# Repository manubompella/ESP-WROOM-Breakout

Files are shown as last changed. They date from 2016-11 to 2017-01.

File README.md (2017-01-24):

# ESP-WROOM-Breakout
Breakouts for ESP8266 and ESP32 WiFi/WLAN + Bluetooth modules from Espressif.
*Note: AI-Thinker ESP-13 is compatible with Espressif ESP-WROOM-02 and AI-Thinker ESP-32S is compatible with Espressif ESP-WROOM-32.*

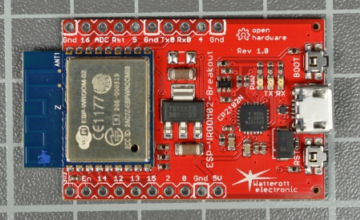
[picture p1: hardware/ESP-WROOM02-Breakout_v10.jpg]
ESP-WROOM02-Breakout (http://www.watterott.com/en/ESP-WROOM02-Breakout)

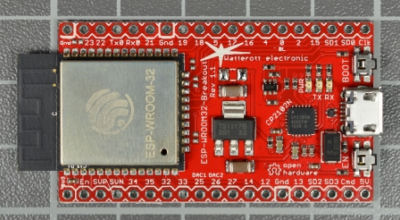
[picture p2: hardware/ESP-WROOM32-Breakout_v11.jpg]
ESP-WROOM32-Breakout (http://www.watterott.com/en/ESP-WROOM32-Breakout)


## Shop
* [ESP-WROOM-02-Breakout (ESP8266)](http://www.watterott.com/en/ESP-WROOM02-Breakout)
* [ESP-WROOM-32-Breakout (ESP32)](http://www.watterott.com/en/ESP-WROOM32-Breakout)

## Features
* Espressif [ESP8266 ESP-WROOM-02](http://espressif.com/en/products/hardware/esp8266ex/overview) WiFi module
* Espressif [ESP32 ESP-WROOM-32](http://espressif.com/en/products/hardware/esp32/overview) WiFi+Bluetooth module
* WiFi standard: IEEE 802.11b/g/n 2.4GHz
* WiFi security: WEP, WPA, WPA2, WAPI
* WiFi Direct and Soft-AP (Access-Point mode)
* Classic and BLE Bluetooth (ESP32)
* Silabs [CP2102N](http://www.silabs.com/products/interface/usb-bridges/usbxpress-usb-bridges/Pages/usbxpress-usb-bridges.aspx) USB UART Bridge (up to 3M baud)
* microUSB-Connector

## Hardware and Software
* [Schematics + Layout](https://github.com/watterott/ESP-WROOM-Breakout/tree/master/hardware)
* ESP8266: [Arduino Core](https://github.com/esp8266/Arduino) (Board: NodeMCU v1)
* ESP32: [Arduino Core](https://github.com/espressif/arduino-esp32) (Board: ESP32 Dev Module)
* [Silabs Serial Port Driver (VCP)](http://www.silabs.com/products/mcu/pages/usbtouartbridgevcpdrivers.aspx)

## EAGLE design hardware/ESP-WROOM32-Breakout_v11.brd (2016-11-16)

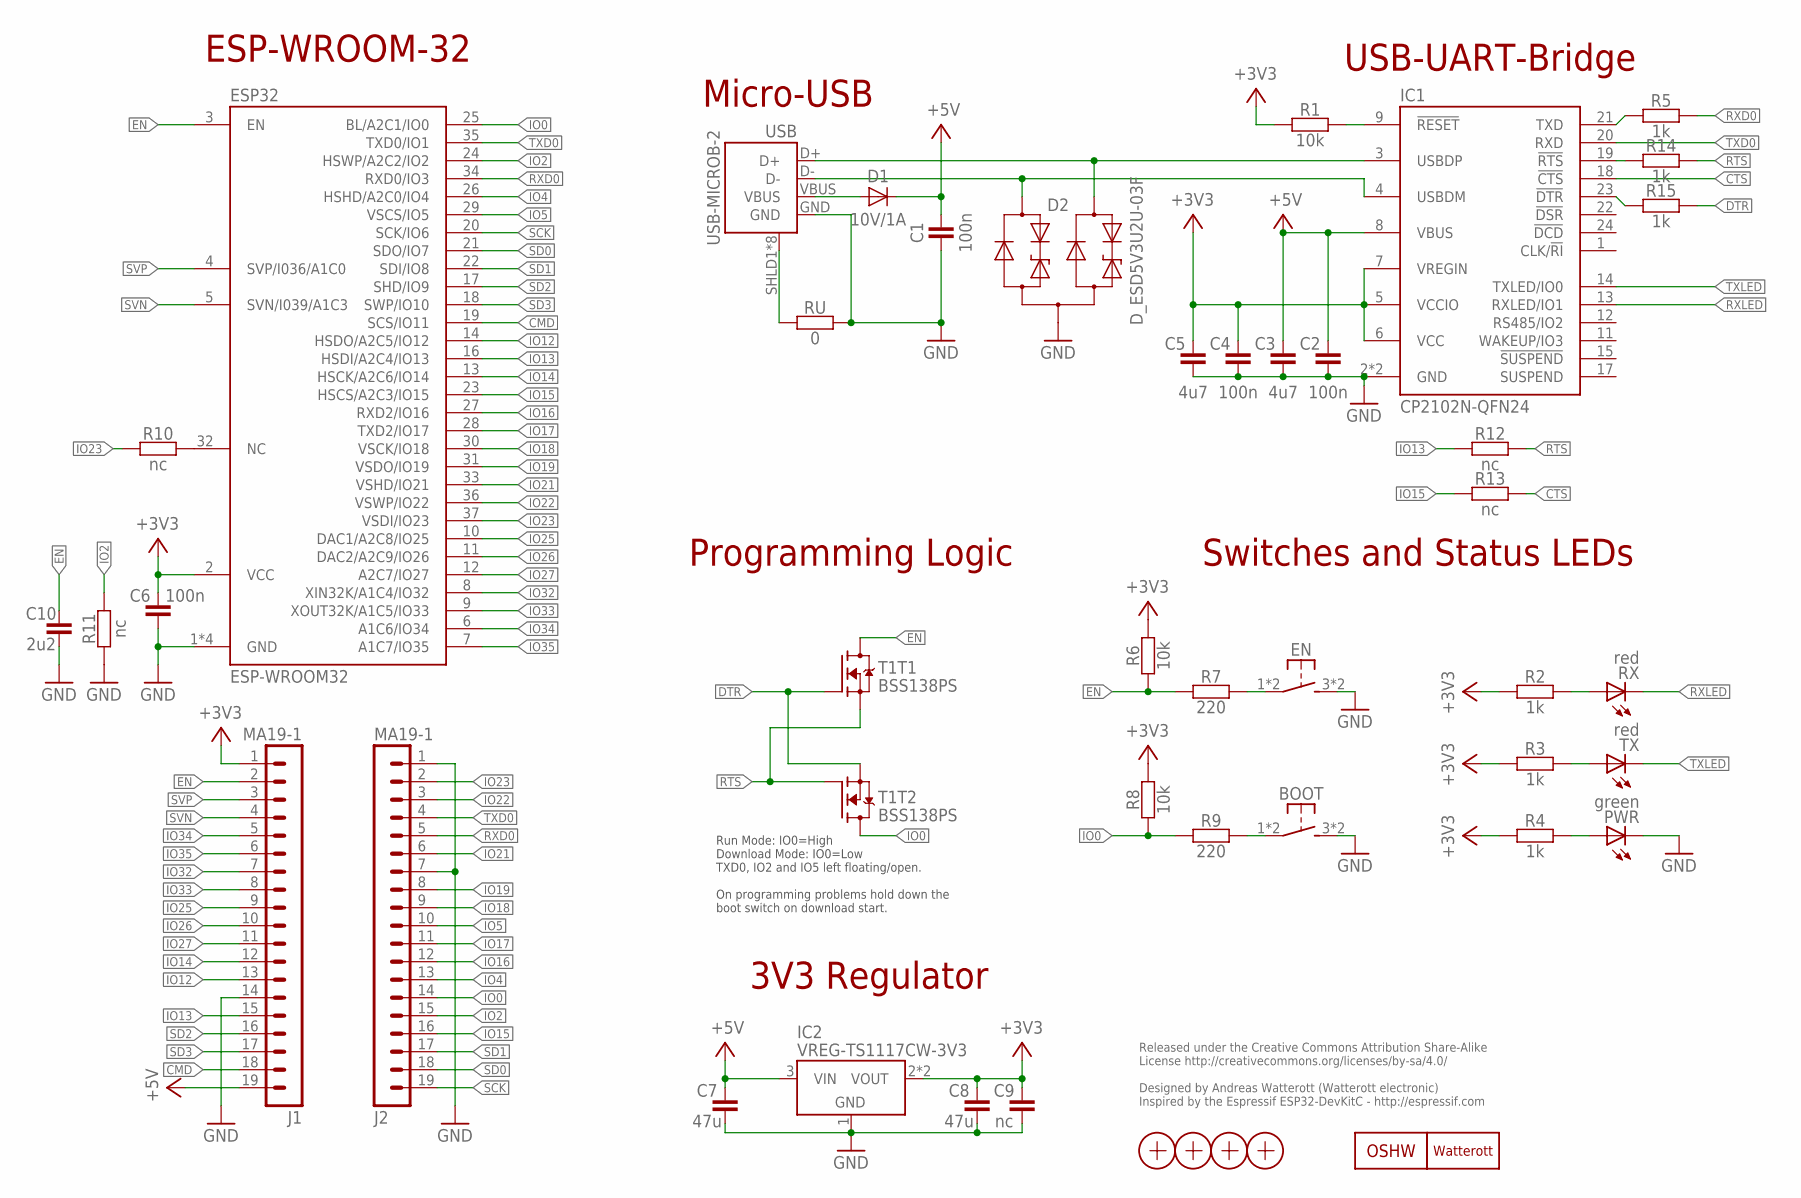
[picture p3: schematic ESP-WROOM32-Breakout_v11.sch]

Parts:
BOOT: SW-TACTILE-PTS840P; PTS840P
C1, C2, C4, C6: 100n; C0402
C3, C5: 4u7; C0603
C7, C8: 47u; C1206
C9: nc; C1206
C10: 2u2; C0402
D1: 10V/1A; SMA_DO214AC
D2: D_ESD5V3U2U-03F; SOT723
EN: SW-TACTILE-PTS840P; PTS840P
ESP32: ESP-WROOM32
IC1: CP2102N-QFN24; QFN24-PAD
IC2: VREG-TS1117CW-3V3; SOT223
J1, J2: MA19-1
LOGO2: OSHW_LOGOX0070; OSHW_6X70
LOGO4: LOGO-S_PLACE_M; SPARK_TPLACE_M
PWR: green; C0603
R1, R6, R8: 10k; C0402
R2, R3, R4, R5, R14, R15: 1k; C0402
R7, R9: 220; C0402
R10, R11, R12, R13: nc; C0402
RU: 0; C0402
RX: red; C0603
T1: BSS138PS; SOT363
TX: red; C0603
USB: USB-MICROB-2; USB-MICROB-10118194
X1, X2, X3, X4: PASSER-07; PASSER_07MM

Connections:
+3V3: C4.2, C5.2, C6.2, C8.2, C9.2, ESP32.2 (VCC), IC1.5 (VCCIO), IC1.6 (VCC), IC1.7 (VREGIN), IC2.2 (VOUT), IC2.4 (VOUT), J1.1, R1.1, R2.1, R3.1, R4.1, R6.2, R8.2
+5V: C1.2, C2.2, C3.2, C7.2, D1.C, IC1.8 (VBUS), IC2.3 (VIN), J1.19
CMD: ESP32.19 (SCS/IO11), J1.18
CPDTR: IC1.23 (!DTR), R15.1
CPRTS: IC1.19 (!RTS), R14.1
CPTX: IC1.21 (TXD), R5.1
CTS: IC1.18 (!CTS), R13.2
DTR: R15.2, T1.2 (G), T1.4 (S)
D_N: D2.1 (C1), IC1.4 (USBDM), USB.D-
D_P: D2.2 (C2), IC1.3 (USBDP), USB.D+
EN: C10.2, ESP32.3 (EN), J1.2, R6.1, R7.1, T1.6 (D)
GND: BOOT.3 (S1), BOOT.4 (S1), C1.1, C2.1, C3.1, C4.1, C5.1, C6.1, C7.1, C8.1, C9.1, C10.1, D2.3 (A), EN.3 (S1), EN.4 (S1), ESP32.1 (GND), ESP32.15 (GND), ESP32.38 (GND), ESP32.TP (GND), IC1.2 (GND), IC1.TP (GND), IC2.1 (GND), J1.14, J2.1, J2.7, PWR.C, R11.1, RU.2, USB.GND
IO0: ESP32.25 (BL/A2C1/IO0), J2.14, R8.1, R9.1, T1.3 (D)
IO2: ESP32.24 (HSWP/A2C2/IO2), J2.15, R11.2
IO4: ESP32.26 (HSHD/A2C0/IO4), J2.13
IO5: ESP32.29 (VSCS/IO5), J2.10
IO12: ESP32.14 (HSDO/A2C5/IO12), J1.13
IO13: ESP32.16 (HSDI/A2C4/IO13), J1.15, R12.1
IO14: ESP32.13 (HSCK/A2C6/IO14), J1.12
IO15: ESP32.23 (HSCS/A2C3/IO15), J2.16, R13.1
IO16: ESP32.27 (RXD2/IO16), J2.12
IO17: ESP32.28 (TXD2/IO17), J2.11
IO18: ESP32.30 (VSCK/IO18), J2.9
IO19: ESP32.31 (VSDO/IO19), J2.8
IO21: ESP32.33 (VSHD/IO21), J2.6
IO22: ESP32.36 (VSWP/IO22), J2.3
IO23: ESP32.37 (VSDI/IO23), J2.2, R10.1
IO25: ESP32.10 (DAC1/A2C8/IO25), J1.9
IO26: ESP32.11 (DAC2/A2C9/IO26), J1.10
IO27: ESP32.12 (A2C7/IO27), J1.11
IO32: ESP32.8 (XIN32K/A1C4/IO32), J1.7
IO33: ESP32.9 (XOUT32K/A1C5/IO33), J1.8
IO34: ESP32.6 (A1C6/IO34), J1.5
IO35: ESP32.7 (A1C7/IO35), J1.6
unnamed: EN.1, EN.2 (P1), R7.2
unnamed: BOOT.1, BOOT.2 (P1), R9.2
NC: ESP32.32 (NC), R10.2
PWR-LED: PWR.A, R4.2
RESET: IC1.9 (!RESET), R1.2
RTS: R12.2, R14.2, T1.1 (S), T1.5 (G)
RX-LED: R2.2, RX.A
RXD0: ESP32.34 (RXD0/IO3), J2.5, R5.2
RXLED: IC1.13 (RXLED/IO1), RX.C
SCK: ESP32.20 (SCK/IO6), J2.19
SD0: ESP32.21 (SDO/IO7), J2.18
SD1: ESP32.22 (SDI/IO8), J2.17
SD2: ESP32.17 (SHD/IO9), J1.16
SD3: ESP32.18 (SWP/IO10), J1.17
SHLD: RU.1, USB.SHLD1 (SHIELD), USB.SHLD2 (SHIELD), USB.SHLD3 (SHIELD), USB.SHLD4 (SHIELD), USB.SHLD5 (SHIELD), USB.SHLD6 (SHIELD), USB.SHLD7 (SHIELD), USB.SHLD8 (SHIELD)
SVN: ESP32.5 (SVN/I039/A1C3), J1.4
SVP: ESP32.4 (SVP/I036/A1C0), J1.3
TX-LED: R3.2, TX.A
TXD0: ESP32.35 (TXD0/IO1), IC1.20 (RXD), J2.4
TXLED: IC1.14 (TXLED/IO0), TX.C
VBUS: D1.A, USB.VBUS

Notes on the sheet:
Released under the Creative Commons Attribution Share-Alike License http://creativecommons.org/licenses/by-sa/4.0/ Designed by Andreas Watterott (Watterott electronic) Inspired by the Espressif ESP32-DevKitC - http://espressif.com
USB-UART-Bridge
Micro-USB
Switches and Status LEDs
Programming Logic
ESP-WROOM-32
3V3 Regulator
Run Mode: IO0=High Download Mode: IO0=Low TXD0, IO2 and IO5 left floating/open. On programming problems hold down the boot switch on download start.

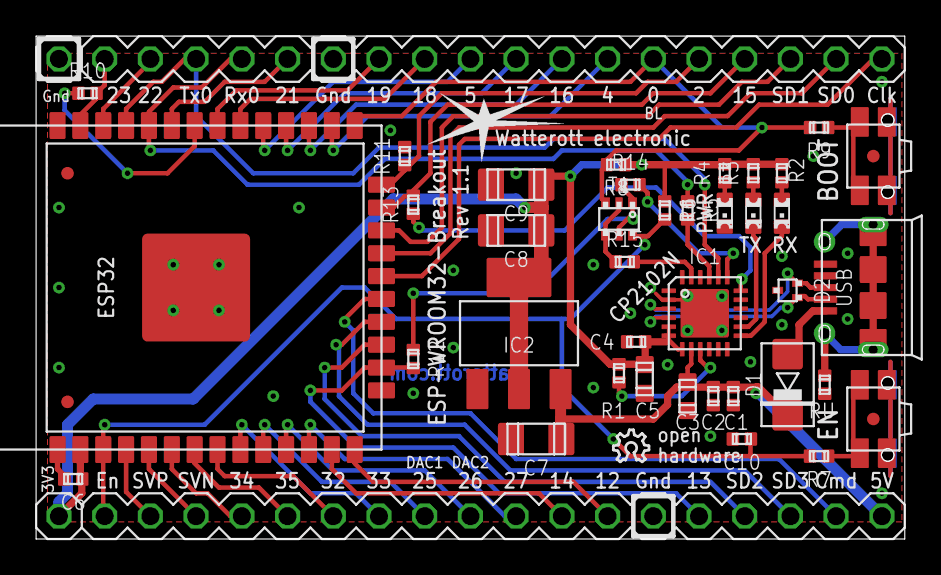
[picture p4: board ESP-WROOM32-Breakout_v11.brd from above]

Board: 2 copper layers, 48.3 x 27.9 mm, 46 parts (0 on the bottom side), 55 nets.

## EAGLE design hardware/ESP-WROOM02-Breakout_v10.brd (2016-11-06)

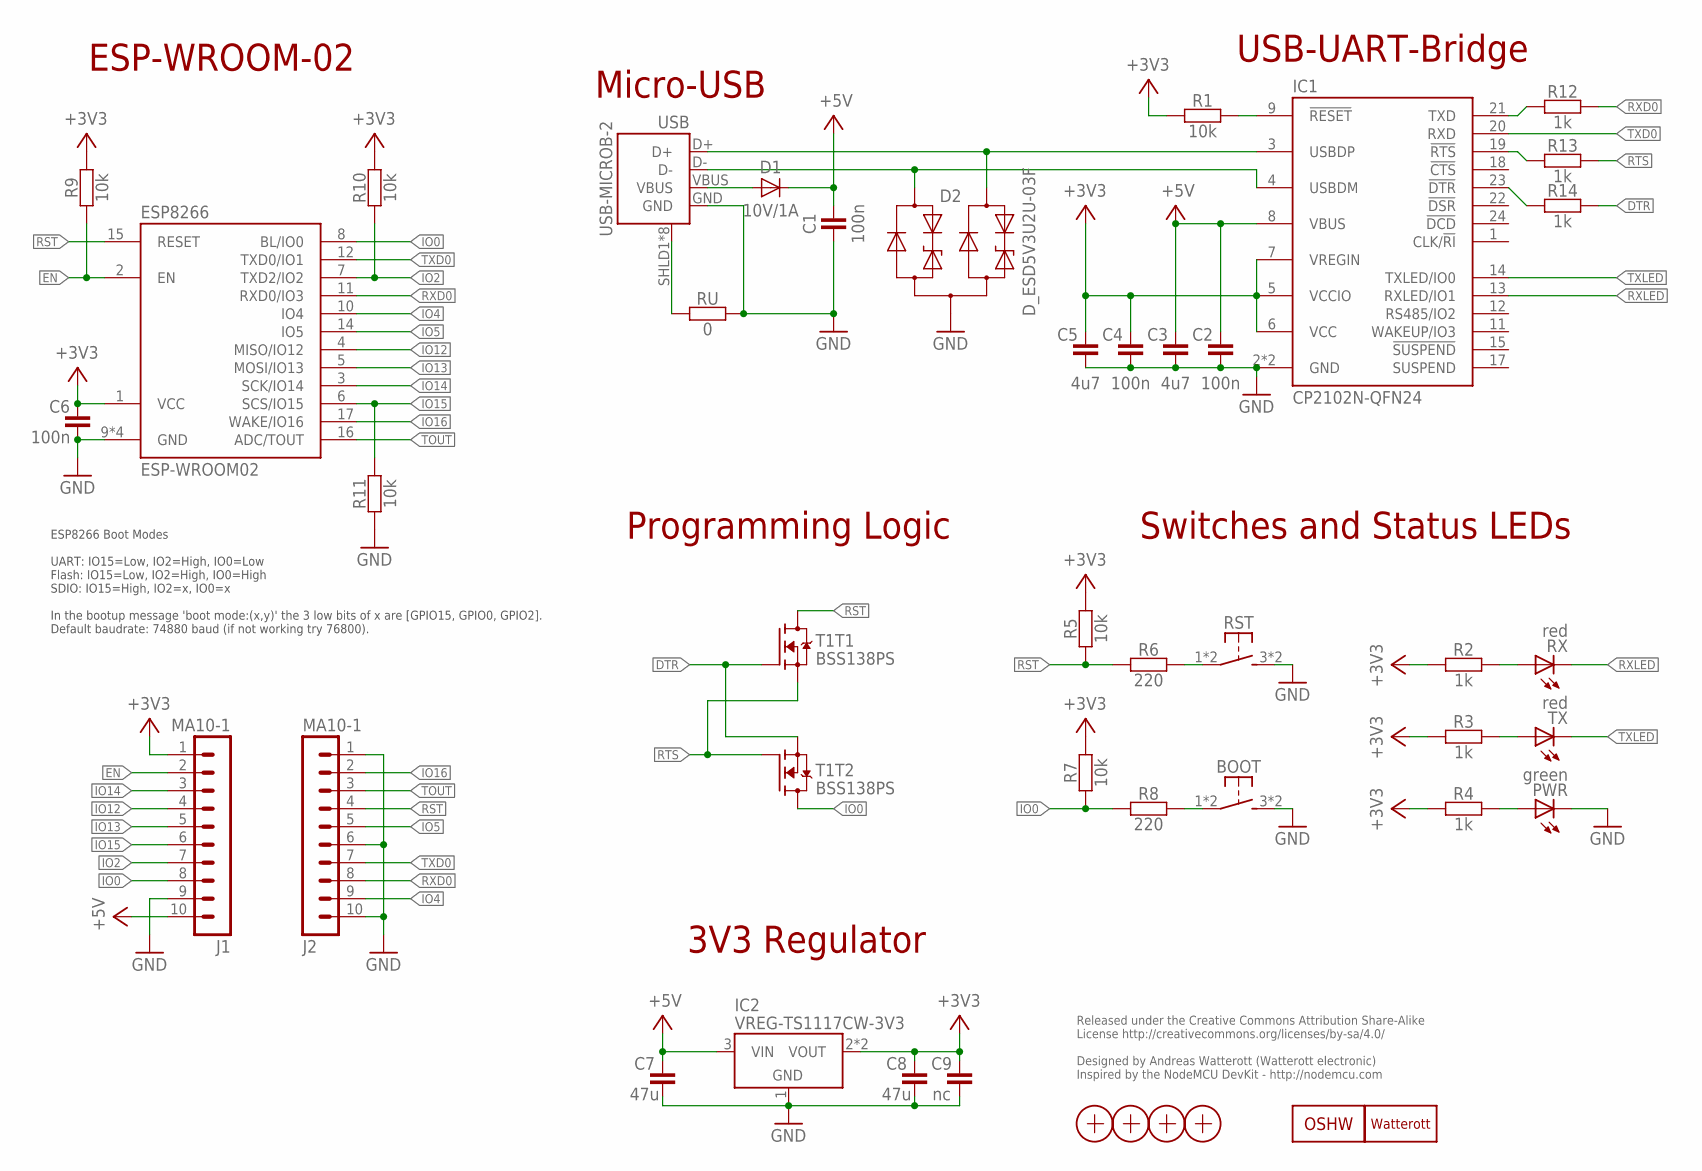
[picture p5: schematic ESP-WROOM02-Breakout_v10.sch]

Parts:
BOOT: SW-TACTILE-PTS840P; PTS840P
C1, C2, C4, C6: 100n; C0402
C3, C5: 4u7; C0603
C7, C8: 47u; C1206
C9: nc; C1206
D1: 10V/1A; SMA_DO214AC
D2: D_ESD5V3U2U-03F; SOT723
ESP8266: ESP-WROOM02
IC1: CP2102N-QFN24; QFN24-PAD
IC2: VREG-TS1117CW-3V3; SOT223
J1, J2: MA10-1
LOGO2: OSHW_LOGOX0070; OSHW_6X70
LOGO4: LOGO-S_PLACE_M; SPARK_TPLACE_M
PWR: green; C0603
R1, R5, R7, R9, R10, R11: 10k; C0402
R2, R3, R4, R12, R13, R14: 1k; C0402
R6, R8: 220; C0402
RST: SW-TACTILE-PTS840P; PTS840P
RU: 0; C0402
RX: red; C0603
T1: BSS138PS; SOT363
TX: red; C0603
USB: USB-MICROB-2; USB-MICROB-10118194
X1, X2, X3, X4: PASSER-07; PASSER_07MM

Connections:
+3V3: C4.2, C5.2, C6.2, C8.2, C9.2, ESP8266.1 (VCC), IC1.5 (VCCIO), IC1.6 (VCC), IC1.7 (VREGIN), IC2.2 (VOUT), IC2.4 (VOUT), J1.1, R1.1, R2.1, R3.1, R4.1, R5.2, R7.2, R9.2, R10.2
+5V: C1.2, C2.2, C3.2, C7.2, D1.C, IC1.8 (VBUS), IC2.3 (VIN), J1.10
CPDTR: IC1.23 (!DTR), R14.1
CPRTS: IC1.19 (!RTS), R13.1
CPTX: IC1.21 (TXD), R12.1
DTR: R14.2, T1.2 (G), T1.4 (S)
D_N: D2.1 (C1), IC1.4 (USBDM), USB.D-
D_P: D2.2 (C2), IC1.3 (USBDP), USB.D+
EN: ESP8266.2 (EN), J1.2, R9.1
GND: BOOT.3 (S1), BOOT.4 (S1), C1.1, C2.1, C3.1, C4.1, C5.1, C6.1, C7.1, C8.1, C9.1, D2.3 (A), ESP8266.9 (GND), ESP8266.13 (GND), ESP8266.18 (GND), ESP8266.TP (GND), IC1.2 (GND), IC1.TP (GND), IC2.1 (GND), J1.9, J2.1, J2.6, J2.10, PWR.C, R11.1, RST.3 (S1), RST.4 (S1), RU.2, USB.GND
IO0: ESP8266.8 (BL/IO0), J1.8, R7.1, R8.1, T1.3 (D)
IO2: ESP8266.7 (TXD2/IO2), J1.7, R10.1
IO4: ESP8266.10 (IO4), J2.9
IO5: ESP8266.14 (IO5), J2.5
IO12: ESP8266.4 (MISO/IO12), J1.4
IO13: ESP8266.5 (MOSI/IO13), J1.5
IO14: ESP8266.3 (SCK/IO14), J1.3
IO15: ESP8266.6 (SCS/IO15), J1.6, R11.2
IO16: ESP8266.17 (WAKE/IO16), J2.2
unnamed: R6.2, RST.1, RST.2 (P1)
unnamed: BOOT.1, BOOT.2 (P1), R8.2
PWR-LED: PWR.A, R4.2
RESET: IC1.9 (!RESET), R1.2
RST: ESP8266.15 (RESET), J2.4, R5.1, R6.1, T1.6 (D)
RTS: R13.2, T1.1 (S), T1.5 (G)
RX-LED: R2.2, RX.A
RXD0: ESP8266.11 (RXD0/IO3), J2.8, R12.2
RXLED: IC1.13 (RXLED/IO1), RX.C
SHLD: RU.1, USB.SHLD1 (SHIELD), USB.SHLD2 (SHIELD), USB.SHLD3 (SHIELD), USB.SHLD4 (SHIELD), USB.SHLD5 (SHIELD), USB.SHLD6 (SHIELD), USB.SHLD7 (SHIELD), USB.SHLD8 (SHIELD)
TOUT: ESP8266.16 (ADC/TOUT), J2.3
TX-LED: R3.2, TX.A
TXD0: ESP8266.12 (TXD0/IO1), IC1.20 (RXD), J2.7
TXLED: IC1.14 (TXLED/IO0), TX.C
VBUS: D1.A, USB.VBUS

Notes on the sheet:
Released under the Creative Commons Attribution Share-Alike License http://creativecommons.org/licenses/by-sa/4.0/ Designed by Andreas Watterott (Watterott electronic) Inspired by the NodeMCU DevKit - http://nodemcu.com
USB-UART-Bridge
Micro-USB
Switches and Status LEDs
Programming Logic
ESP-WROOM-02
ESP8266 Boot Modes UART: IO15=Low, IO2=High, IO0=Low Flash: IO15=Low, IO2=High, IO0=High SDIO: IO15=High, IO2=x, IO0=x In the bootup message 'boot mode:(x,y)' the 3 low bits of x are [GPIO15, GPIO0, GPIO2]. Default baudrate: 74880 baud (if not working try 76800).
3V3 Regulator

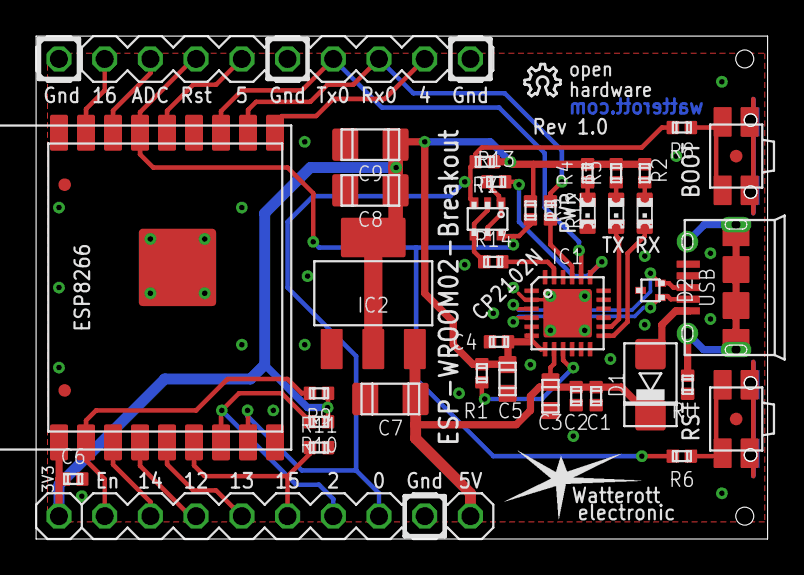
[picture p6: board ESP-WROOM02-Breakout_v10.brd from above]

Board: 2 copper layers, 40.6 x 27.9 mm, 44 parts (0 on the bottom side), 34 nets.

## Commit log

2016-11-06 added layout and schematics
    [ESP-WROOM02-Breakout_v10.brd, ESP-WROOM02-Breakout_v10.sch, ESP-WROOM32-Breakout_v10.brd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]
2016-11-08 updated schematics
    [ESP-WROOM32-Breakout_v10.sch]
2016-11-16 added rev 1.1
    [ESP-WROOM32-Breakout_v11.brd, ESP-WROOM32-Breakout_v11.sch]
